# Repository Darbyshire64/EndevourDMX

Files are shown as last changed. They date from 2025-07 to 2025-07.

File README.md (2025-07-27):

# EndevourDMX
This is a custom DMX Tranciver Platform Designed for both reciving and controling DMX. Using an ESP32-C3 With Onboard WIFI

>[!Warning]
> Use This PCB at your own Risk. I cannot take liability if it breake's and or causes damage to equipment. This has not been tested and there is no garrentee of upholding to any level of quality/functionality.

https://github.com/user-attachments/assets/77d9e712-4af0-4d90-8f60-33b776832eaa

## Curently Availible Firmware Modes
  - Cable Tester
  - Light Controler

## Goals
  - Control One DMX Universe
  - Recive DMX and make signal qaulity Reports.
  - WIFI Based Control.
  - Display Status and Other INFO With Inbuilt OLED

## How It Works

It allows for DMX Passthrough so if something where to hapen to the MCU the DMX signal Could still passthrough pasiveley without power. The A,B Data lines are protected by a TVS Diode and 100 ohm resistors this cleans up any interfearence in the transmision. this is then sent the the MAX845E Chip to convert the data into easy to recive serieal data for the ESP. As the DMX lighting protocol uses RS845 Serieal the MAX845E is neccesary to control TX/RX the signal.

# Photos
## PCB



## Case




# BOM

I know this BOM is Expensive But its cheaper than the equivlent device i was trying to redesign but better, Called MyDMX 3.0 witch is 401.74 USD

<a href="https://www.djkit.com/products/american-dj-mydmx-30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"> LINK </a>

| QTY | Item | Price | Link |
|-----|---|---|---|
| | PCB Total | $14.59  | |
| | Component Total | $38.81 | |
| | Case Total | $4.50 | |
| | Misc Total | $13.36 | |
| | Total | $71.27 | |

## PCB 

| QTY | Item | Price | Link |
|-----|---|---|---|
|  5  | Custom Blue LF HASL PCB | $9.40  | |
| | Shipping (GSDL) | $5.19 | |
| | Total | $14.59  | |

## Components

I have chosen Digikey because it has all of my components vs LCSC who has a few of my components in stock as of making the BOM. it would be more cost effective  to buy all the components in one go rather than by two lots of shipping and handeling fees. and A OLEDs components are cheaper via Ali Express.

### Digikey
| QTY | Item | Price  | Link |
|-----|---|---|---|
|  2  | 1.5KE15CA | $0.34 | <a href="https://www.digikey.co.uk/en/products/detail/stmicroelectronics/1-5KE15CA/1037261">LINK</a> |
|  1  | 1N4007 | $0.10 | <a href="https://www.digikey.co.uk/en/products/detail/diotec-semiconductor/1N4007/18833652">LINK</a> |
|  1  | MFR-25FBF52-1K8  | $0.10 | <a href="https://www.digikey.co.uk/en/products/detail/yageo/MFR-25FBF52-1K8/9138063">LINK</a> |
|  1  | CFR-12JB-52-3K3  | $0.10 | <a href="https://www.digikey.co.uk/en/products/detail/yageo/CFR-12JB-52-3K3/3989">LINK</a> |
|  2  | MFR-25FBF52-100R | $0.10 | <a href="https://www.digikey.co.uk/en/products/detail/yageo/MFR-25FBF52-100R/12795">LINK</a> |
|  1  | MFR-25FBF52-120R | $0.10 | <a href="https://www.digikey.co.uk/en/products/detail/yageo/MFR-25FTE52-120R/9139747">LINK</a> |
|  1  | 2N3904 | $0.14 | <a href="https://www.digikey.co.uk/en/products/detail/diotec-semiconductor/2N3904/13164701">LINK</a> |
|  3  | WS281B | $0.68 | <a href="https://www.digikey.co.uk/en/products/detail/sparkfun-electronics/16347/11630204">LINK</a> |
|  1  | MAX485ECSA+ | $5.88 | <a href="https://www.digikey.co.uk/en/products/detail/analog-devices-inc-maxim-integrated/MAX485ECSA/1495336">LINK</a> |
|  1  | IO-XLR3-F-EH | $2.63 | <a href="https://www.digikey.co.uk/en/products/detail/io-audio-technologies/IO-XLR3-F-EH/9931888">LINK</a> |
|  1  | IO-XLR3-M-EH | $2.55 | <a href="https://www.digikey.co.uk/en/products/detail/io-audio-technologies/IO-XLR3-M-EH/9931887">LINK</a> |
|  1  | XIAO ESP-32-C3 | $4.99 | <a href="https://www.digikey.co.uk/en/products/detail/seeed-technology-co-ltd/113991054/16652880">LINK</a> |
|  1  | 2.4Ghz Atenna | $2.20 | <a href="https://www.digikey.co.uk/en/products/detail/seeed-technology-co-ltd/103990623/18724506">LINK</a> |
|  1  | Headers | $0.24 | <a href="https://www.digikey.co.uk/en/products/detail/seeed-technology-co-ltd/102010490/19176770">LINK</a> |
| | Shiping | $6.88 | |
| | Total Excl Shiping| $21.95 | |
| | Total Incl Shiping| $29.84 | |

### AliExpress

| QTY | Item | Price  | Link |
|-----|---|---|---|
|  1  | OLED DISPLAY | $5.35 | <a href="https://www.aliexpress.com/item/1005008988479159.html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">LINK</a> |
| | Total Excl Shiping | $5.35 |
| | Toatl Incl Shiping | $8.34 |

## Case

Printed With Printing Legion. Estmiated Shiping Cost Based on prevoious printing legion experiance.

| QTY | Item | Price | Link |
|-----|---|---|---|
|  1  | Case | $4.50 | |

## Tool's & Misc

| QTY | Item | Price | Link |
|-----|---|---|---|
|  1  | 10g Flux | $3.32 | <a href="https://www.aliexpress.com/item/1005008562727265.html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"> LINK </a> |
|  1  | 50g Solder | $10.89  | <a href="https://www.aliexpress.com/item/1005007330449968.html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"> LINK </a> |
|  1  | M3 Heatset Inserts | $2.03 | <a href="https://www.aliexpress.com/item/1005003582355741.html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"> LINK </a>  |
|  1  | M3x14mm Screws | $2.94 | <a href="https://www.aliexpress.com/item/32867841097.html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"> LINK </a> |
| | Total No Discount & Shiping | $19.81 |
| | Total Incl Discounts & Shiping | $13.36|

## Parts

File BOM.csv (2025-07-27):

QTY | Item | Price | Link
5 | Custom Blue LF HASL PCB | $9.40
2 | 1.5KE15CA | $0.34 | https://www.digikey.co.uk/en/products/detail/stmicroelectronics/1-5KE15CA/1037261
1 | 1N4007 | $0.10 | https://www.digikey.co.uk/en/products/detail/diotec-semiconductor/1N4007/18833652
1 | MFR-25FBF52-1K8 | $0.10 | https://www.digikey.co.uk/en/products/detail/yageo/MFR-25FBF52-1K8/9138063
1 | CFR-12JB-52-3K3 | $0.10 | https://www.digikey.co.uk/en/products/detail/yageo/CFR-12JB-52-3K3/3989
2 | MFR-25FBF52-100R | $0.10 | https://www.digikey.co.uk/en/products/detail/yageo/MFR-25FBF52-100R/12795
1 | MFR-25FBF52-120R | $0.10 | https://www.digikey.co.uk/en/products/detail/yageo/MFR-25FTE52-120R/9139747
1 | 2N3904 | $0.14 | https://www.digikey.co.uk/en/products/detail/diotec-semiconductor/2N3904/13164701
3 | WS281B | $0.68 | https://www.digikey.co.uk/en/products/detail/sparkfun-electronics/16347/11630204
1 | MAX485ECSA+ | $5.88 | https://www.digikey.co.uk/en/products/detail/analog-devices-inc-maxim-integrated/MAX485ECSA/1495336
1 | IO-XLR3-F-EH | $2.63 | https://www.digikey.co.uk/en/products/detail/io-audio-technologies/IO-XLR3-F-EH/9931888
1 | IO-XLR3-M-EH | $2.55 | https://www.digikey.co.uk/en/products/detail/io-audio-technologies/IO-XLR3-M-EH/9931887
1 | XIAO ESP-32-C3 | $4.99 | https://www.digikey.co.uk/en/products/detail/seeed-technology-co-ltd/113991054/16652880
1 | 2.4Ghz Atenna | $2.20 | https://www.digikey.co.uk/en/products/detail/seeed-technology-co-ltd/103990623/18724506
1 | Headers | $0.24 | https://www.digikey.co.uk/en/products/detail/seeed-technology-co-ltd/102010490/19176770
1 | OLED DISPLAY | $5.35 | https://www.aliexpress.com/item/1005008988479159.html?mp=1
1 | Case | $4.50
1 | 10g Flux | $3.32 | https://www.aliexpress.com/item/1005008562727265.html?mp=1
1 | 50g Solder | $10.89 | https://www.aliexpress.com/item/1005007330449968.html?mp=1
1 | M3 Heatset Inserts | $2.03 | https://www.aliexpress.com/item/1005003582355741.html?mp=1
1 | M3x14mm Screws | $2.94 | https://www.aliexpress.com/item/32867841097.html?mp=1

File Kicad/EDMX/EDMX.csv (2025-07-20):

Id | Designator | Footprint | Quantity | Designation | Supplier and ref
1 | U2 | XIAO-ESP32C3-DIP | 1 | XIAO-ESP32-C3-DIP
2 | Q1 | TO-92_Inline | 1 | 2N3904
3 | J1 | Jack_XLR_Neutrik_NC3MAAH_Horizontal | 1 | XLR3 IN
4 | R4,R5 | R_Axial_DIN0207_L6.3mm_D2.5mm_P7.62mm_Horizontal | 2 | 100Ω
5 | R1 | R_Axial_DIN0207_L6.3mm_D2.5mm_P7.62mm_Horizontal | 1 | 3.3kΩ
6 | J2 | SSD1306-0.91-OLED-4pin-128x32 | 1 | Conn_01x04
7 | R2 | R_Axial_DIN0207_L6.3mm_D2.5mm_P7.62mm_Horizontal | 1 | 1.8kΩ
8 | D3,D2 | D_DO-201AE_P15.24mm_Horizontal | 2 | 1.5KExxCA
9 | D6 | LED_WS2812B_PLCC4_5.0x5.0mm_P3.2mm | 1 | Light Control
10 | D4 | LED_WS2812B_PLCC4_5.0x5.0mm_P3.2mm | 1 | DMX Status
11 | J3 | Jack_XLR_Neutrik_NC3FAH2_Horizontal | 1 | XLR3 OUT
12 | D1 | D_DO-34_SOD68_P10.16mm_Horizontal | 1 | D
13 | U1 | DIP-8_W7.62mm | 1 | MAX485E
14 | R3 | R_Axial_DIN0207_L6.3mm_D2.5mm_P7.62mm_Horizontal | 1 | 120Ω
15 | D5 | LED_WS2812B_PLCC4_5.0x5.0mm_P3.2mm | 1 | WiFi Status

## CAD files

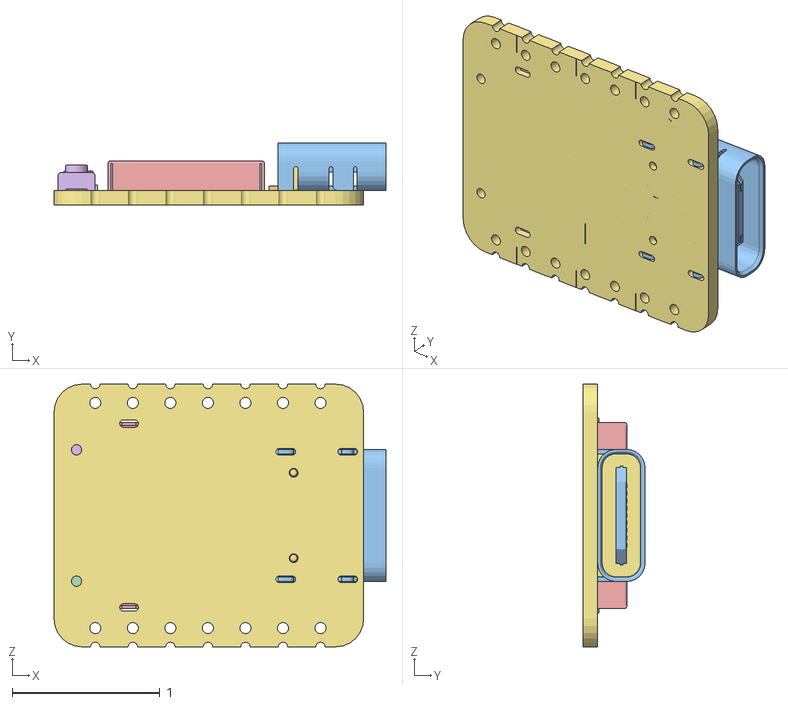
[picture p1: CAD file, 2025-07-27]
3D Models/XIAO-ESP-32-C3.obj
2.25 x 0.421 x 1.78

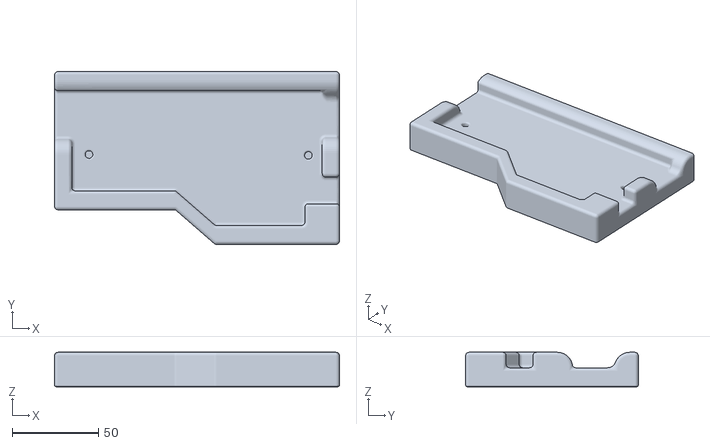
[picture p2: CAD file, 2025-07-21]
Production/Case/EndevourDMX-Case.stl
165.0 x 100.0 x 20.0

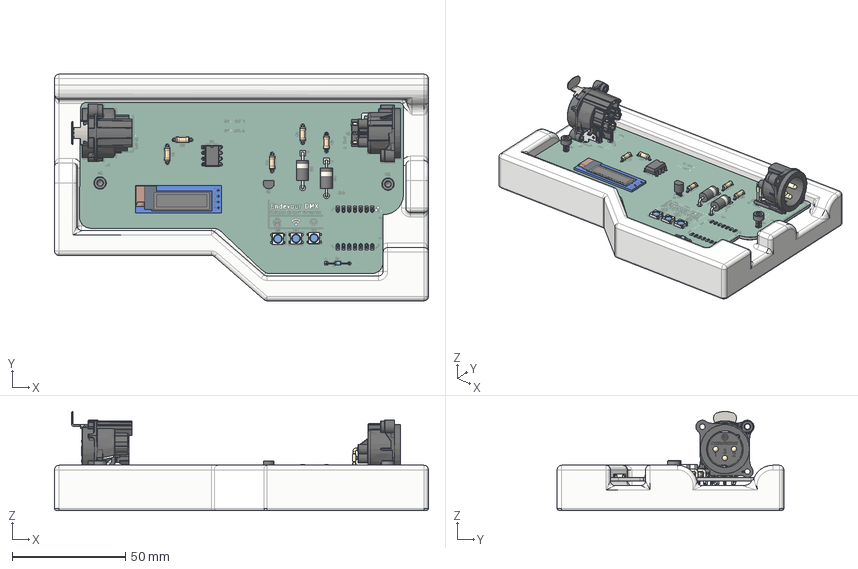
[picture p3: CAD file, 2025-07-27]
3D Models/EndevourDMX.step
165.0 x 100.0 x 43.7 mm
TO-92_Inline
Neutrik NC3MAH-0
R_Axial_DIN0207_L6.3mm_D2.5mm_P7.62mm_Horizontal x 5
0.91in oled Module - Board
0.91in OLED - Folded Flush - Without Glass
0603 Capacitor x 9
0603 Resistor x 5
SOT23-3
Diode (SOD-323)
D_DO-201AE_P15.24mm_Horizontal x 2
LED_WS2812B_PLCC4_5.0x5.0mm_P3.2mm x 3
Neutrik NC3FAH2
D_DO-34_SOD68_P10.16mm_Horizontal
DIP-8_W7.62mm
EDMX_copper
EDMX_pad
EDMX_via
EDMX_silkscreen
EDMX_soldermask
EDMX_PCB
DIN_912-M3x16 x 2

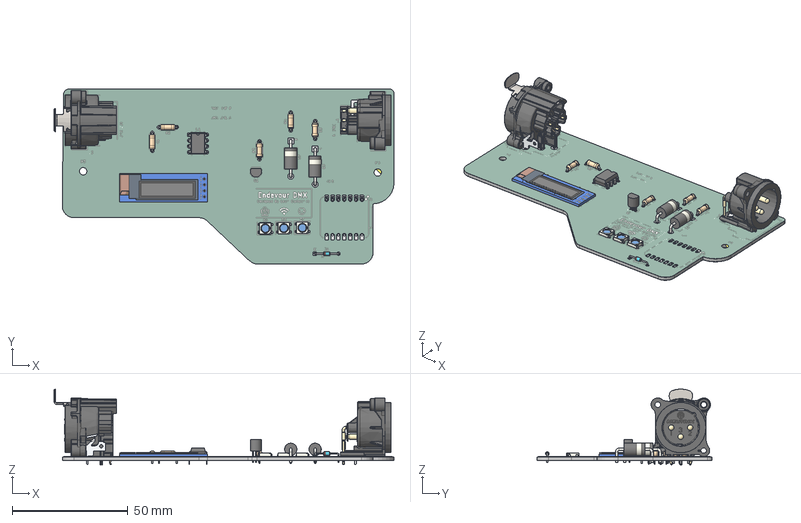
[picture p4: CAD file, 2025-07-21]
3D Models/PCB.step
146.6 x 75.5 x 32.7 mm
TO-92_Inline
Neutrik NC3MAH-0
R_Axial_DIN0207_L6.3mm_D2.5mm_P7.62mm_Horizontal x 5
0.91in oled Module - Board
0.91in OLED - Folded Flush - Without Glass
0603 Capacitor x 9
0603 Resistor x 5
SOT23-3
Diode (SOD-323)
D_DO-201AE_P15.24mm_Horizontal x 2
LED_WS2812B_PLCC4_5.0x5.0mm_P3.2mm x 3
Neutrik NC3FAH2
D_DO-34_SOD68_P10.16mm_Horizontal
DIP-8_W7.62mm
EDMX_copper
EDMX_pad
EDMX_via
EDMX_silkscreen
EDMX_soldermask
EDMX_PCB

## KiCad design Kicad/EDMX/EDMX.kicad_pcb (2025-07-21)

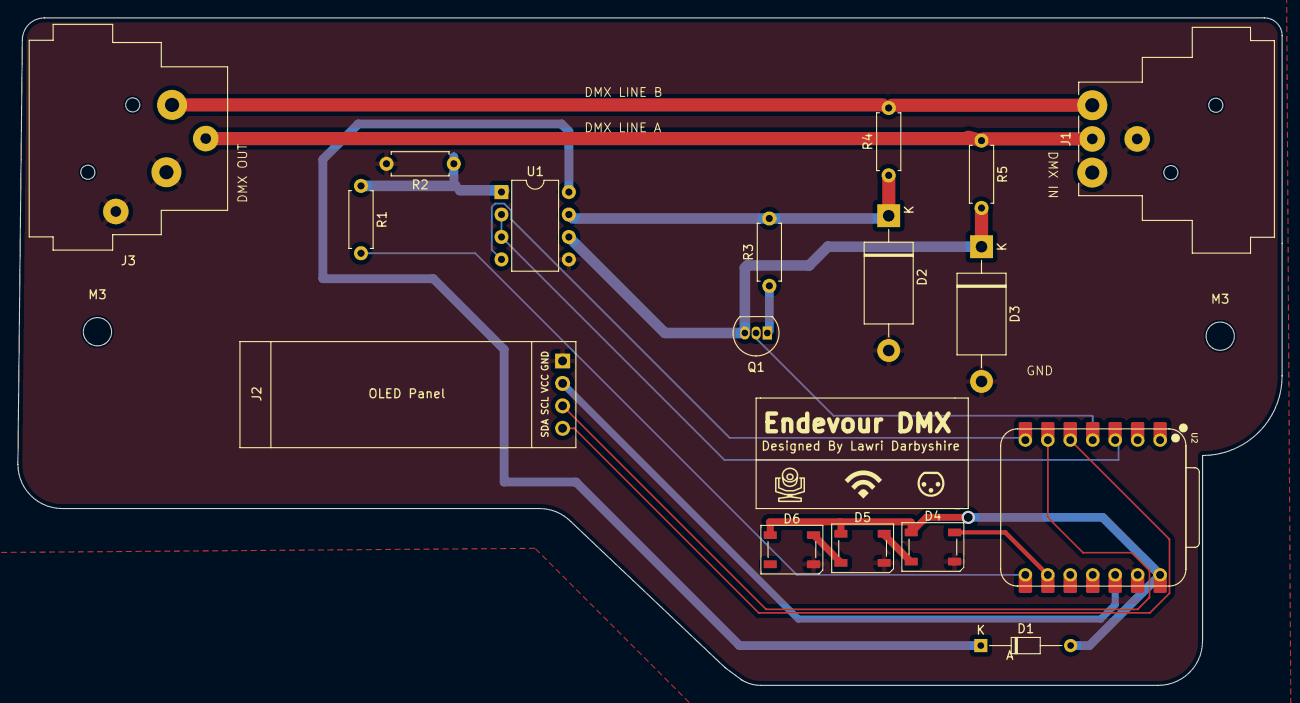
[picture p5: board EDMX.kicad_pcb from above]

Board: 2 copper layers, 143.0 x 75.5 mm, 19 parts (0 on the bottom side), 18 nets.

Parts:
D1: D; D_DO-34_SOD68_P10.16mm_Horizontal
D2, D3: 1.5KExxCA; D_DO-201AE_P15.24mm_Horizontal
D4: DMX Status; LED_WS2812B_PLCC4_5.0x5.0mm_P3.2mm
D5: WiFi Status; LED_WS2812B_PLCC4_5.0x5.0mm_P3.2mm
D6: Light Control; LED_WS2812B_PLCC4_5.0x5.0mm_P3.2mm
J1: XLR3 IN; Jack_XLR_Neutrik_NC3MAAH_Horizontal
J2: Conn_01x04; SSD1306-0.91-OLED-4pin-128x32
J3: XLR3 OUT; Jack_XLR_Neutrik_NC3FAH2_Horizontal
M3, M3#2: MountingHole_3.2mm_M3
Q1: 2N3904; TO-92_Inline
R1: 3.3kΩ; R_Axial_DIN0207_L6.3mm_D2.5mm_P7.62mm_Horizontal
R2: 1.8kΩ; R_Axial_DIN0207_L6.3mm_D2.5mm_P7.62mm_Horizontal
R3: 120Ω; R_Axial_DIN0207_L6.3mm_D2.5mm_P7.62mm_Horizontal
R4, R5: 100Ω; R_Axial_DIN0207_L6.3mm_D2.5mm_P7.62mm_Horizontal
U1: MAX485E; DIP-8_W7.62mm
U2: XIAO-ESP32-C3-DIP; XIAO-ESP32C3-DIP

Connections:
/5V: R1.1, R2.1, U1.1 (RO)
GND: D2.2 (A2), D3.2 (A2), D4.3 (VSS), D5.3 (VSS), D6.3 (VSS), J1.1, J1.G, J2.1, J3.1, J3.G, R2.2, U1.5 (GND), U2.13 (GND)
unnamed: D2.1 (A1), R3.2, R4.2
unnamed: D3.1 (A1), Q1.3 (C), R5.2, U1.6 (A)
unnamed: D4.2 (DOUT), D5.4 (DIN)
unnamed: D5.2 (DOUT), D6.4 (DIN)
unnamed: J1.2, J3.2, R4.1
unnamed: J1.3, J3.3, R5.1
unnamed: Q1.1 (E), R3.1
RX: R1.2, U2.8 (GPIO20/D7/RX)
SCL: J2.3, U2.6 (GPIO7/D5/SCL)
SDA: J2.4, U2.5 (GPIO6/D4/SDA)
STATUS LIGHTS: D4.4 (DIN), U2.9 (GPIO8/D8/SCK)
TERM CONTROL: Q1.2 (B), U2.4 (GPIO5/A3/D3)
TX: U1.4 (DI), U2.7 (GPIO21/D6/TX)
TX/RX Control: U1.2 (~RE), U1.3 (DE), U2.3 (GPIO4/A2/D2)
VBUS: D1.1 (K), D1.2 (A), D4.1 (VDD), D5.1 (VDD), D6.1 (VDD), U1.8 (VCC), U2.14 (VBUS)
VCC: J2.2, U2.12 (VCC_3V3)

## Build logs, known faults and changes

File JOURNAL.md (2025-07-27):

---
title: "EndevourDMX" 
author: "Lawri Darbyshire"
description: "This is a custom DMX Tranciver Platform Designed for both reciving and controling DMX (A Stage Lighting Protocol). Using an ESP32-C3 With Onboard WIFI"
created_at: "2025-07-15"
---

# Planing 
(2 hrs)
Along time ago - 14/07/25
(Ive been thinking about this for a long time.)

I often do stage lighting for both my Drama Class and School Events. i wanted something i could use to diagnose lights. give me live data and more.
in order to do this i looked at hooking up a Seed Studio XIAO ESP32-C3, that had built in WIFI,  to a intercept a DMX signal and proccess it. so i researched more about this.
i discovered that DMX Uses RS845 as it is based on MIDI witch is serial. So after a bit of researching i settled on taking the DMX signal and
parsing it through a MAX845E Chip to allow it to be controlled VIA the GPIO of the ESP32. i also then started to think about the formfactor
would it be a Square like the MYDMX 3 Box. but after being inspired by The Wolf on slacks Cable tester i settled on  a Rectangular Design. THE PCB is
very Compact and Functional only Allows as much room as needed for the components whilst still maintaining a nice Shape and design.  Later that day i began work on the PCB.

# The PCB

## Day 1 - PCB DESIGN 
(3 hrs)
(14/07/25)

I worked on the PCB. I already new the components i needed. and after finding diagrams online i managed to get the schematic done. it took a lot of effort. 
i often setup the TX side of things but completely forgot i would be RX aswell. After all these mistakes by the Night i had finished the Schematic



## Day 2 - PCB DESIGN 
(4 hrs)
(15/07/2025)

Today  I spent alot of time working on the PCB and getting all the components layed out. i made a lot of progress working extra hard to get everything done quickly as of witting its 30mins past midnight for me.
will probably go over this in the morning with a fresh mind and fix all the spelling mistakes. But after a lot of work i completed the PCB. initially started work on this yesterday as a personal project but eventualy i decided i would like do this for highway to get some more points so i havent got the KiCAD source files in here yet but will migrate them at a later date. 

# Day 3 - PCB Design 
(3 hrs)
(18/07/2025) 

I Spent time changeing the width of all the traces to match the voltage. thanks to guidance from @Krunch on slack. i added a ground plane to remove the Unessary winding GND trace around my pcb. this also reduces noise from the 5V to Data Lines. as well as if theres a Surge on one of the lines then it will go to ground before any critical components. i also spent the later half of the evening researching components on JLC PCB's Library. I also thought some status lights would be necessary for my PCB so i added 3 Neo Pixels  That correspond to there silk screen icons above.



# Day 4 - PCB Design 
(3 hrs)
(19/07/2025) 

Today i found all the parts in the JLC Parts List and put them on to a table on the READEME.md. I also uploaded my PCB Gerber's to JLC PCB and calculated the cost of my PCB. i decided Due to me handeling data i wanted EING for high performance and also wanted the PCB to look high quality so EING was the obvious choice. ive also recently liked white PCB so chose that.



# Day 5 - Case Design 
(4 hrs)
(20/07/2025)

I designed the case and and finished up the BOM. I moved everything back to Digikey Because PCBA Became ridiculously expensive. I also changed back to HASL. for the case I just did a simple open top design to make mounting the pcb and printing easy. I may have gone abit crazy with the fillet.



# Day 6 - Firmware 
(2hrs)
(21/07/2025)

So today I thought that the PCB and Case where pretty much finished. so I decided to move onto the firmware. for the firmware i just wanted to start off with a simple  mode cable testing. tommorow i will probably work on an actual control mode.



# Day 7 - Firmware 
(2hrs)
(25/07/2025)

Utilizing the Pre-exsisting firmware i wrote on Day 6 i researched how to control the ESP-32's C3 Wifi chip. so now this new firmware makes an Wifi Network and hosts a web server. With faders to control the ligts. im just making simple firmware for now but im going to add more modes tommorrow.



# Day 8 -
(4 hrs) (7hrs Incl Render Time)
(27/07/2025)

I did some BOM tidying up. and sourced some AliExpress reasearch cutting my BOM by about $20. I then Imported the CAD File into Blender to create a nice Product Reveal Video in blender. And for the 3hrs it took to render. i spent 1 hrs making  some self test firmware. because when i make the product i want a way to test weather my soldering is good. it just runs through Each Np and the display Cycling componenets.



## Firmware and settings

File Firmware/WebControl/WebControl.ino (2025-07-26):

// Import Hardware Control Libraries
#include <Adafruit_NeoPixel.h>
#include <Adafruit_GFX.h>
#include <Adafruit_SSD1306.h>
#include <Wire.h>

// Network Utilites

#include <WiFi.h>
#include <WebServer.h>
#include <Preferences.h>


// Define Pins and Details

// MadMax Control Pins
#define DMX_TX 6
#define DMX_RX 7
#define DMX_DIN 4

// Indicator Setups
#define NP_PIN  2 
#define NP_AMNT 2
Adafruit_NeoPixel pixels(NP_AMNT, NP_PIN, NEO_GRB + NEO_KHZ800);

#define SCRN_WIDTH 128
#define SCRN_HEIGHT 32
#define OLED_SDA 6
#define OLED_SCL 7
#define OLED_RESET -1
#define OLED_ADDR 0x3C
Adafruit_SSD1306 display(SCRN_WIDTH, SCRN_HEIGHT, &Wire, OLED_RESET);

// Setup Network 

WebServer server();
Prefrences prefs;

const char* ap_ssid = "EDMX";
const char* ap_password = "Endevour-512";

void setupAP () {
  WiFi.softAP(ap_ssid, ap_password);
}

// DMX Stuff
HardwareSerial DMX(1);
uint8_t dmxData[512] = {0};

// Functions For the Web Server
void handleRoot() {
  server.send(200, "text/html", R"rawliteral(
    <h1>EDMX</h1>
    <input type='range' min='0' max='255' id='ch1' value='0' oninput='update(1, this.value)>
    <span id='val1'>0</span><br><br>
    <button onclick='saveScene()'>Save Scene</button>
    <script>
    function update(ch, val) {
      document.getElementByID("val" + ch).textContent = val;
      fetch(`/dmx?ch=${ch}&val=${val}`);
    }
    function saveScene() {
      fetch("/save");
    }
    </script>
  )rawliteral");
}

void handleSave() {
  prefs.begin("dmx", false);
  for (int i = 0; 1 < 512; i++) {
    prefs.putUChar(String(i).c_str(), dmxData[i])
  }
  prefs.end();
  server.send(200, "text/plain", "Scene saved");
  pixels.setPixelColor(0, pixels.Color(255,255,0));
  pixels.show();
  delay(500);
  pixels.setPixelColor(0, 0)
  pixels.show();
}

void loadScene() {
  prefs.begin("dmx", true);
  for (int i = 0; i < 512; i++) {
    dmxData[i] = prefs.getUChar(String(i).c_str(), 0);
  }
  prefs.end();
}

// DMX Related Functions 
void setupDMX() {
  // Init MadMax
  pinMode(DMX_DIR_PIN, OUTPUT);
  digitalWrite(DMX_DIR_PIN, HIGH);
  DMX.begin(250000, SERIAL_8N2, DMX_RX_PIN, DMX_TX_PIN);
}

void handleDMX() {
  if (server.hasArg("ch") && server.hasArg("val")) {
    int ch = server.arg("ch").toInt();
    int val = server.arg("val").toInt();
    if (ch >= 1 && ch <= 512) {
      dmxData[ch - 1] = val;
    }
    server.send(200, "text/plain", "OK");
  } else {
    server.send(400, "text/plain", "Missing Arg's")
  }
}


void sendDMXFrame() {
  // NEw Frame SIG
  DMX.write(0);
  // Actual Data
  DMX.write(dmxData, 512);
}

// Send Frame
void setup() {
  // Indicator Setup
  Wire.begin(OLED_SCL, OLED_SDA); 
  display.begin(SSD1306_SWITCHAPVCC, 0x3C);
  display.clearDisplay();
  display.setTextSize(1);
  display.setTextColor(SSD1306_WHITE);
  display.setCursor(0,0);
  display.println("EDMX     MODE:LC")
  display.println("STATUS:  Starting ")
  display.println("Your Endevour is Starting...")
  display.display();

  pixels.begin();
  pixels.clear();
  pixels.setPixelColor(1, pixels.Color(0,0,255));
  pixels.show();


  // INIT Wifi
  setupAP();
  
  pixels.setPixelColor(1, pixels.Color(255,0,0));
  pixels.show();

  pixels.setPixelColor(0, pixels.Color(0,0,255));
  setupDMX();
  loadScene();
  pixels.setPixelColor(0, pixels.Color(255,0,0));

  server.on("/", handleRoot);
  server.on("/dmx", handleDMX);
  server.on("/save", handleSave);
  server.begin();

  pixels.setPixelColor(2, pixels.Color(255,0,0));

  display.clearDisplay();
  display.setCursor(0,0);
  display.println("EDMX     MODE:LC")
  display.println("STATUS:  READY")
  display.println("IP:      192.168.4.1")
}

void loop() {
  server.handleClient();
  sendDMXFrame();
  delay(25);
}

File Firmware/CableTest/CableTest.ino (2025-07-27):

#include <Adafruit_NeoPixel.h>
#include <Adafruit_GFX.h>
#include <Adafruit_SSD1306.h>
#include <Wire.h>


// define pins 
#define DMX_TX 6
#define DMX_RX 7
#define DMX_DIN 4
#define NP_PIN  2 
#define NP_AMNT 2
#define SCRN_WIDTH 128
#define SCRN_HEIGHT 32
#define OLED_SDA 6
#define OLED_SCL 7
#define OLED_RESET -1
#define OLED_ADDR 0x3C

//SETUP NP
Adafruit_NeoPixel strip(NP_AMNT, NP_PIN, NEO_GRB + NEO_KHZ800);
Adafruit_SSD1306 display(SCRN_WIDTH, SCRN_HEIGHT, &Wire, OLED_RESET);

// helper script

//Remder text to Display
void showMessage(string line1, string line2 = "") {
  display.clearDisplay();
  display.setCursor(0,0);
  display.setTextSize(1);
  display.SetTextColor(SSD1306_WHITE);
  display.println("EndevourDMX - CT Mode");
  display.println(line1);
  if (line2.length() > 0) display.println(line2);
  display.display();
}

// Put Max Into TX Mode
void setTransmitMode() {
  digitalWrite(DMX_DIR, HIGH);
}

// Put Max Into RX Mode
void setTransmitMode() {
  digitalWrite(DMX_DIR, LOW);
}

void setup() {
  //DMX Setup
  pinMode(DMX_DIR, OUTPUT);
  setTransmit();

  // INT NP
  strip.begin();
  strip.clear();
  strip.show();
  strip.setPixelColor(0, strip.color(0,0,255));
  strip.setPixelColor(1, strip.color(0,0,255));
  strip.setPixelColor(2, strip.color(0,0,255));

  // INT OLED
  Wire.begin():
  display.begin(SSD1306_SWITCHAPVCC, OLED_ADDR);
  display.display();
  delay(1000);
  display.clearDisplay();
  display.display();

  //UART
  Serial1.begin(250000, SERIAL_8N, DMX_RX, DMX_TX);
  showMessage("Waiting for test...");
  delay(500);
}

// Test Loop
void loop() {
  strip.setPixelColor(0, strip.color(255,255,255));
  strip.setPixelColor(1, strip.color(0,0,0));
  strip.setPixelColor(2, strip.color(0,0,0));

  showMessage("Cable...");

  //Transmit Byte
  setTransmit();
  delayMicroseconds(50);
  Serial1.write(0);
  Serial1.write(123);
  Serial1.flush();
  delay(5);

  //Recive
  setRecive();
  delay(5);

  bool success = false;
  int b1 = -1, b2 = -1

  if (Serial1.available() >= 2) {
    b1 = Serial1.read();
    b2 = Serial1.read();
    if (b2 == 123) success = true;
  }

  if (success) {
    setPixel(0, strip.Color(255,0,0));
    showMessage("Cable... OK")
  } else {
    setPixel(0, strip.Color(0,255,0));
    showMessage("Cable... BROKEN")
  }
  delay(1500)
}

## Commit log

2025-07-16 Added KiCAD Project
    [EDMX.kicad_pcb, EDMX.kicad_sch]
2025-07-21 Updated Journal and moved the files about
    [BOM.csv, EDMX.kicad_pcb, EndevourDMX-Case.stl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]
2025-07-27 Added New Fully Assembled PCB Model
    [Endevour DMX_.step]
2025-07-27 Made Render
    [ES32.obj]
2025-07-27 Renamed Files
    [EndevourDMX.step, XIAO-ESP-32-C3.obj]
